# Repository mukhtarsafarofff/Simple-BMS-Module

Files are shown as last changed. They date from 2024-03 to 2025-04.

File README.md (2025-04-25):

(ENG) To control the process of charging and discharging of Lithium ion or LiPo batteries, they will stop working or worse. The battery cells can swell and even explode from overcharging, and a deep discharge can make the battery fail.  That’s why these batteries should go together with a battery management system unit or BMS. This will control the voltage and current from the battery and keep them safe. The nominal voltage of a LIPO battery is 3.8 volts and 4.2V when fully charged. As soon as the battery cell will reach this value, the charging process should stop and that’s what this circuit should do. When we have only one cell, we only care about the maximum voltage and the current limit to protect the battery. But when we have a battery pack of more than 1 cell, so 2S, 3S and so on, we also need to balance the value of each individual cell.  At the base of the transistor, we have a ZENNER reference diode (TL431) which will get open at a certain voltage value and by that connects ground to the transistors base and when the transistor is active, we bypass the battery and waste the power on the diodes instead. This ZENNER diode is the TL431 and it has a reference pin, so by adjusting the potentiometer we can set this reference to be at 4.2V, that’s how we select when the charging process will stop. To test the circuit , I  use a battery which is discharged and below 4.2V (it was 3.8V). When I connect it to the charger, the LED is turned off. I have a current flow of around 450 mA and the battery is getting charged up. After some time, when we get above4.16V the LED will turn ON so the charging process is complete. Current is now flowing through the diodes and transistor and we skip the battery, so the cell is protected for over voltage. 

(DEU) Um den Lade- und Entladevorgang von Lithium-Ionen- oder LiPo-Batterien zu steuern, müssen sie richtig überwacht werden, sonst funktionieren sie nicht oder es kann noch schlimmer kommen.  Die Batteriezellen können bei Überladung anschwellen und sogar explodieren, und eine Tiefentladung kann die Batterie unbrauchbar machen. Deshalb sollten diese Batterien immer zusammen mit einer Batterie-Management-System-Einheit (BMS) verwendet werden.  Diese steuert die Spannung und den Strom der Batterie und hält sie sicher. Die Nennspannung einer LiPo-Batterie beträgt 3,8 Volt und 4,2 Volt, wenn sie vollständig geladen ist. Sobald die Batteriezelle diesen Wert erreicht, sollte der Ladevorgang gestoppt werden, und genau das soll diese Schaltung tun. Wenn wir nur eine Zelle haben, kümmern wir uns nur um die maximale Spannung und den Stromgrenzwert, um die Batterie zu schützen. Aber wenn wir ein Batteriepack mit mehr als einer Zelle haben, also 2S, 3S und so weiter, müssen wir auch den Wert jeder einzelnen Zelle ausbalancieren. An der Basis des Transistors haben wir eine Z-Dioden-Referenz (TL431), die bei einem bestimmten Spannungswert öffnet und damit die Basis des Transistors mit Masse verbindet. Wenn der Transistor aktiv ist, umgehen wir die Batterie und verbrauchen die Energie stattdessen an den Dioden. Diese Z-Diode ist die TL431 und sie hat einen Referenzpin. Durch Einstellen des Potentiometers können wir diese Referenz auf 4,2 Volt einstellen, wodurch wir festlegen, wann der Ladevorgang gestoppt wird. Um die Schaltung zu testen, benutze ich eine Batterie, die entladen ist und unter 4,2 Volt liegt (sie hatte 3,8 Volt). Wenn ich sie an das Ladegerät anschließe, ist die LED ausgeschaltet. Ich habe einen Stromfluss von etwa 450 mA und die Batterie wird aufgeladen.  Nach einiger Zeit, wenn wir über 4,16 Volt erreichen, wird die LED eingeschaltet, sodass der Ladevorgang abgeschlossen ist. Der Strom fließt jetzt durch die Dioden und den Transistor und wir umgehen die Batterie, sodass die Zelle vor Überspannung geschützt ist.

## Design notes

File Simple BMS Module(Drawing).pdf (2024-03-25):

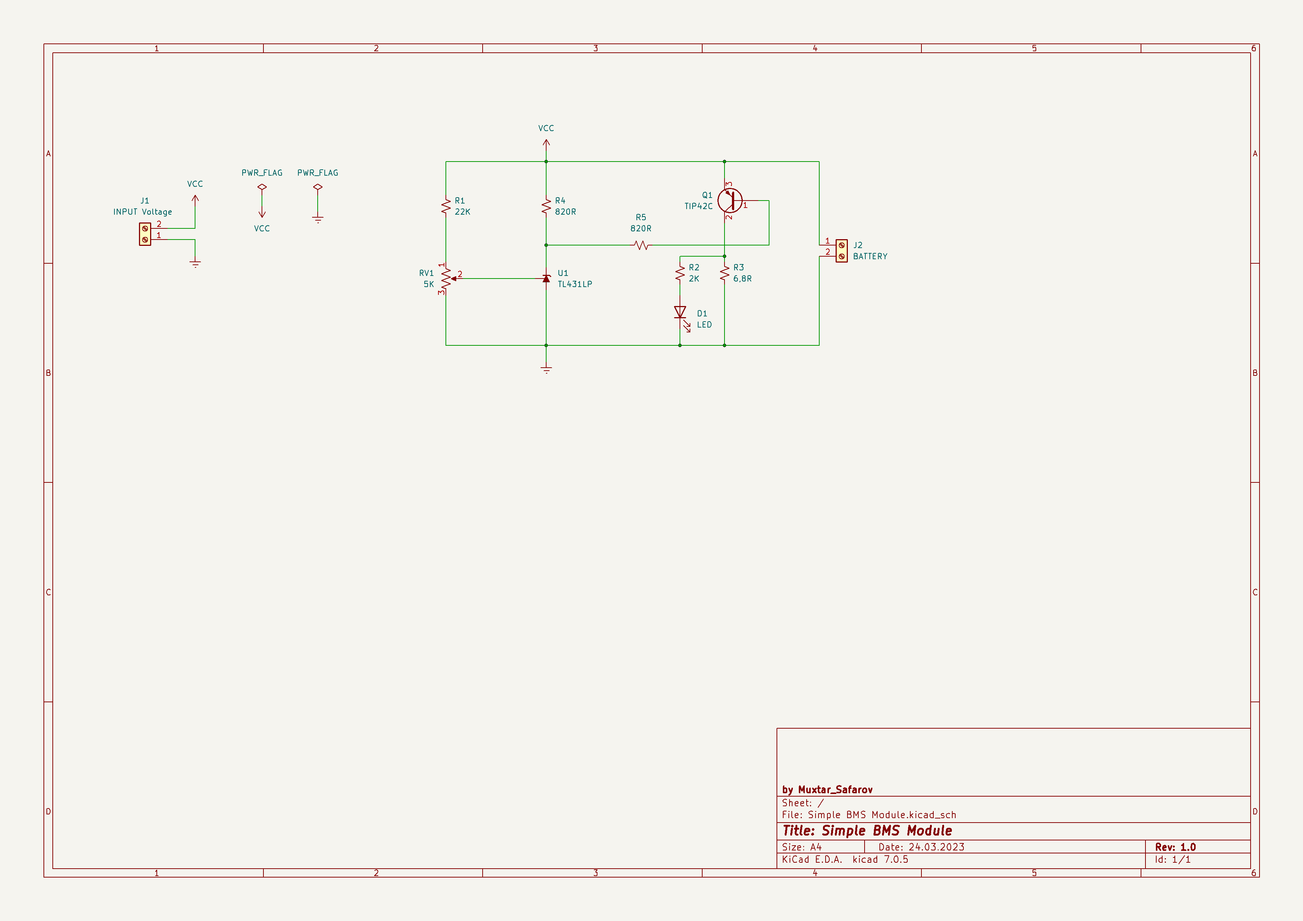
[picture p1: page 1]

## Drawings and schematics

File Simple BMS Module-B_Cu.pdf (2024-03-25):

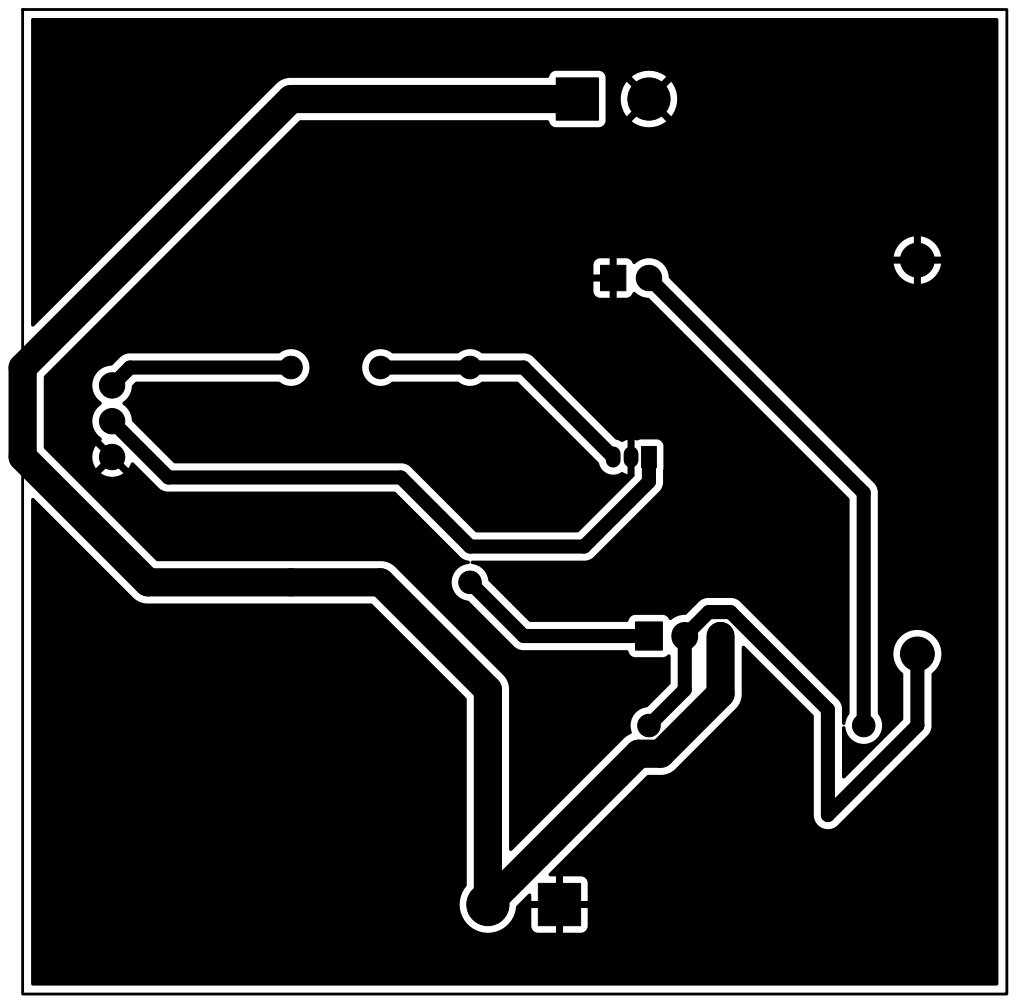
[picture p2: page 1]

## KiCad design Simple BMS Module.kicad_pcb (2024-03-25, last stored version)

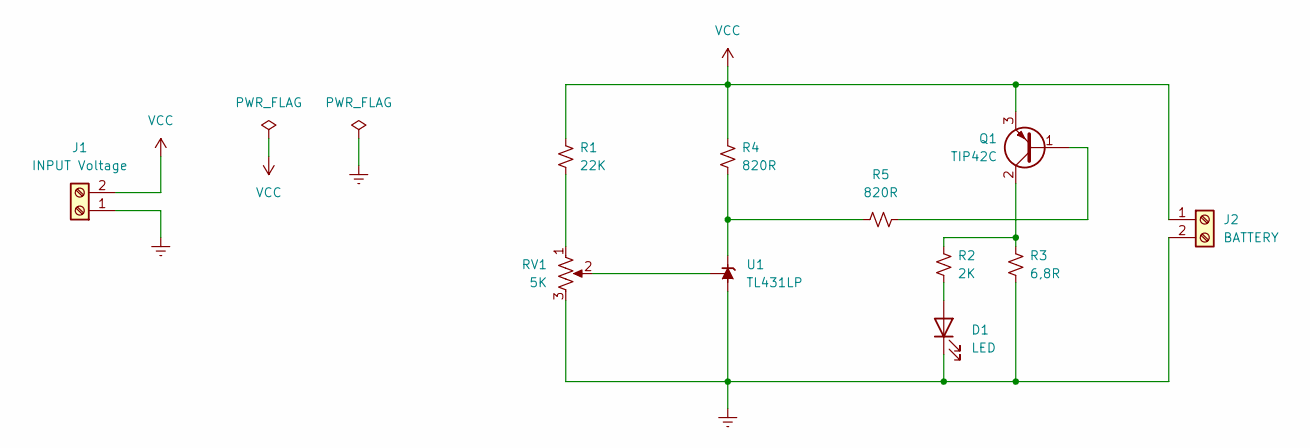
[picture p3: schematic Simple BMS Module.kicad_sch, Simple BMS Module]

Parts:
D1: LED; LED_D5.0mm
J1: INPUT Voltage; TerminalBlock_bornier-2_P5.08mm
J2: BATTERY; TerminalBlock_bornier-2_P5.08mm
Q1: TIP42C; TO-220-3_Vertical
R1: 22K; R_Axial_DIN0207_L6.3mm_D2.5mm_P15.24mm_Horizontal
R2: 2K; R_Axial_DIN0207_L6.3mm_D2.5mm_P15.24mm_Horizontal
R3: 6,8R; R_Axial_Power_L25.0mm_W9.0mm_P27.94mm
R4, R5: 820R; R_Axial_DIN0207_L6.3mm_D2.5mm_P15.24mm_Horizontal
RV1: 5K; Potentiometer_Vishay_148-149_Single_Horizontal
U1: TL431LP; TO-92_Inline

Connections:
Earth: D1.1 (K), J1.1, J2.2, R3.2, RV1.3, U1.2 (A)
unnamed: D1.2 (A), R2.2
unnamed: Q1.1 (B), R5.2
unnamed: Q1.2 (C), R2.1, R3.1
unnamed: R1.2, RV1.1
unnamed: R4.2, R5.1, U1.3 (K)
unnamed: RV1.2, U1.1 (REF)
VCC: J1.2, J2.1, Q1.3 (E), R1.1, R4.1

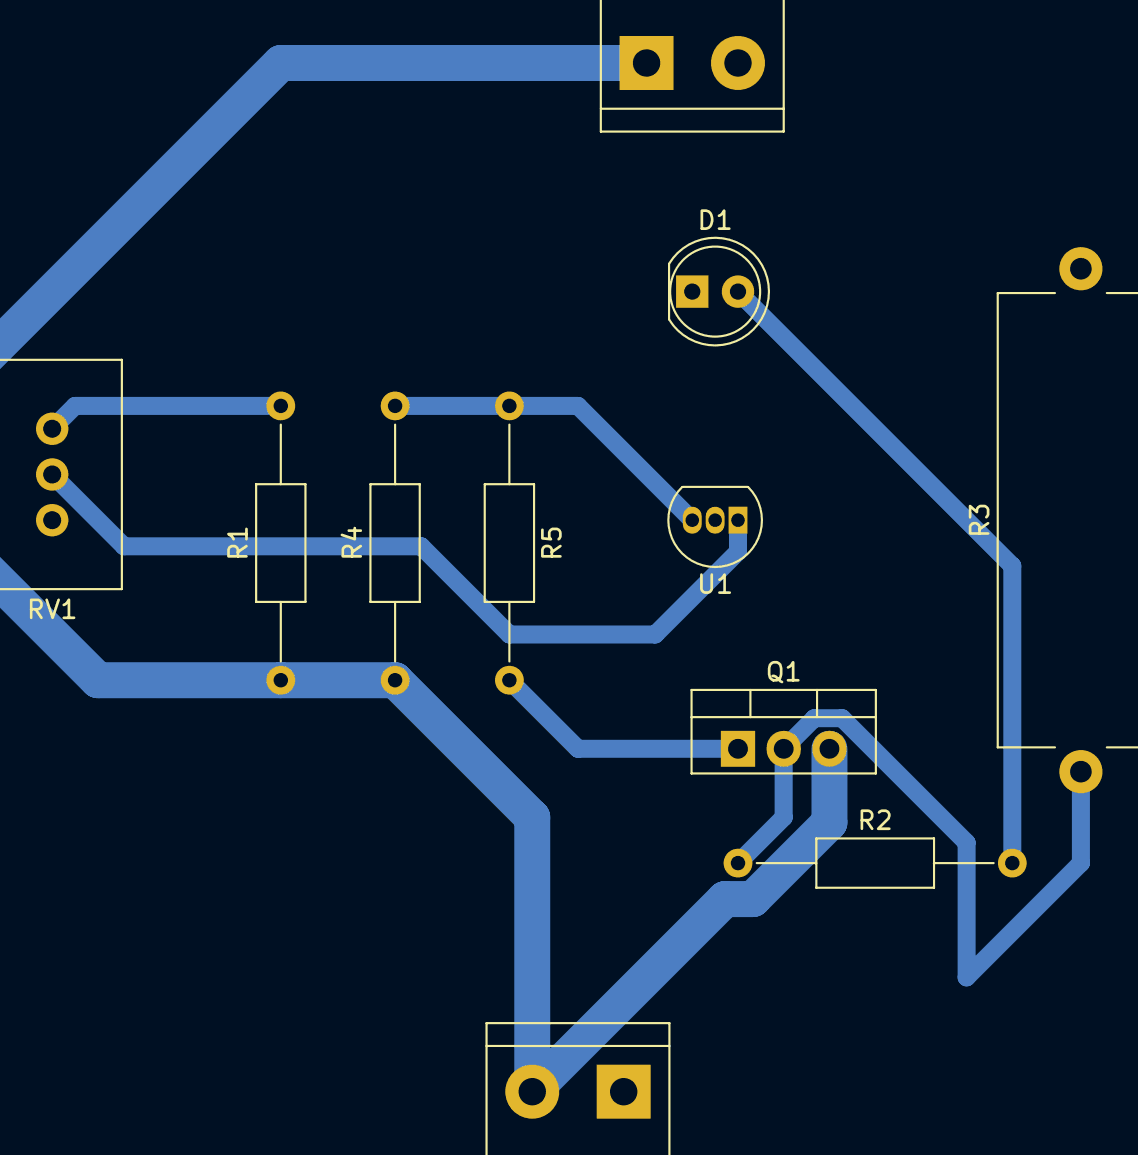
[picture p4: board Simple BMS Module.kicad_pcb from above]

Board: 2 copper layers, 11 parts (0 on the bottom side), 8 nets.

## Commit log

2024-03-20 Simple BMS Module is accomplished
    [Simple BMS Module.kicad_pcb, Simple BMS Module.kicad_sch]
2024-03-20 Simple BMS module is renewed
    [Simple BMS Module.kicad_pcb, Simple BMS Module.kicad_sch]
